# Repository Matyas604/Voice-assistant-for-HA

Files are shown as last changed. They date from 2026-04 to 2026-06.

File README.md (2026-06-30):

# Voice assistant for HA
A while back, I saw a YouTube video about a voice assistant for [Home Assistant](https://www.home-assistant.io/). I really liked that it activates when you say “Hey Jarvis” and can control various things via voice commands. 
And since I have Home Assistant set up, I thought, why not try building that assistant myself?

I found out that voice recognition can run on the [ESP32-S3-WROOM-1-N16R8](https://m5stack-doc.oss-cn-shenzhen.aliyuncs.com/1183/ESP32-S3-WROOM-1U-N16R8.pdf), so I decided to use it because it’s relatively inexpensive. 
Since I also wanted it to have a high-quality speaker for playing music, the total cost is quite high, but that’s because of the speaker, the custom PCB, and other components. 

I really enjoyed working on this project because I learned a lot of new things. For example, I learned how to properly design a speaker enclosure, since sound quality depends more on the enclosure than on the speaker itself.

## Features
- Power and programming are handled via the **USB-C** port on the back
- The [ESP32-S3](https://m5stack-doc.oss-cn-shenzhen.aliyuncs.com/1183/ESP32-S3-WROOM-1U-N16R8.pdf) is the brain of the entire voice assistant
- It uses **Groq AI**, **GroqTTS**, and **Groq STT**, so it can speak and understand many languages
- It's not just a voice assistant for commands, but also a great AI assistant
- It has internet access, so it can search for information and use it to provide answers
- Everything is accompanied by a light response, so you know exactly what's going on
- It's also a great music player because it features a high-quality [DAYTON DMA45-4](https://www.reproobchod.cz/user/related_files/dma45-4.pdf) speaker
- It has a touch button to mute the assistant hidden in the top cover.

<p align="center">
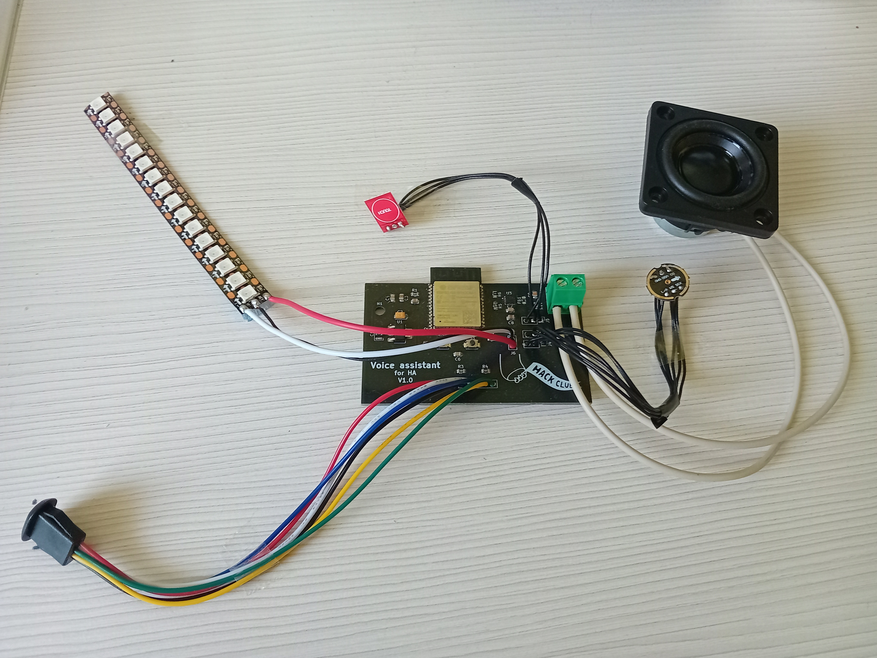
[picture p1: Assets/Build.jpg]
  
</p>

⚠️As you can see, the project is fully functional, but it’s missing the case because I had a few issues with the printer in printing legion and it didn’t arrive in time for the deadline. That’s why I’m submitting it to the build review like this for now, but as soon as the case arrives, I’ll document it again. Thank you

I really enjoyed designing and then building this project, especially because it works absolutely great. There was one error in the PCB (it’s already been corrected in the schematic and files), but fortunately it wasn’t a huge one and was easy to fix. This was actually my first project to include SMD components, and I soldered it by hand. The hardest part was soldering the amplifier chip, but luckily I managed to do it in the end!

Now, here's how it works: Once it's set up correctly, all you have to do is say "Hey Jarvis" and give your command or ask your question, and it will respond immediately or perform the action you requested. [Here](https://github.com/Matyas604/Voice-assistant-for-HA/blob/main/How%20to%20Set%20It%20Up.md) are the complete instructions on how to set it up.

## CAD model
Everything is housed in a box consisting of 5 parts (front panel, rear panel, top panel, body, and a tube connecting the outside to the inside chamber). The touch button is hidden in the top panel, so it can be activated by touch and is not visible from the outside. The interior space behind the speaker must be completely airtight at the front to function properly; it is connected to the outside only by a tube at the back. It is also a good idea to place a piece of cotton wool inside for better sound quality. The PCB is located separately from the space around the speaker; it is secured with M3 screws, just like the rear panel, while the top panel is held in place by magnets. 

<p align="center">
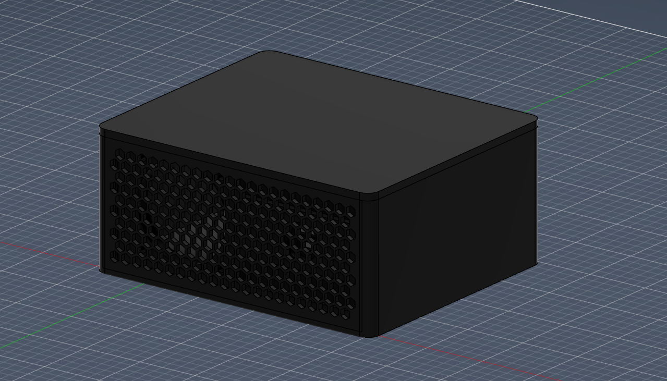
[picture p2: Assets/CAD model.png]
CAD model
  
</p>
<p align="center">
  <strong>Made in Fusion360</strong>
</p>

## PCB
<p align="center">
  Schematic
</p>
<p align="center">
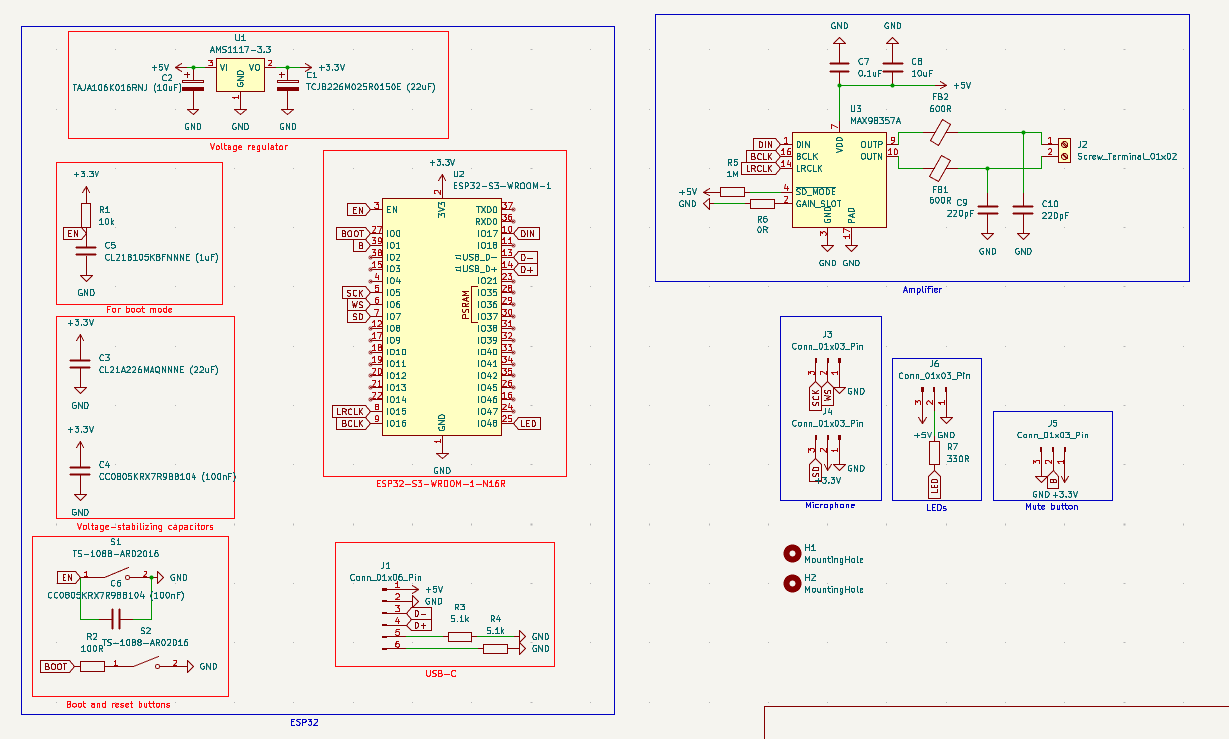
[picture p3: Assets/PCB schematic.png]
PCB schematic
  
</p>
<p align="center">
  PCB
</p>
<p align="center">
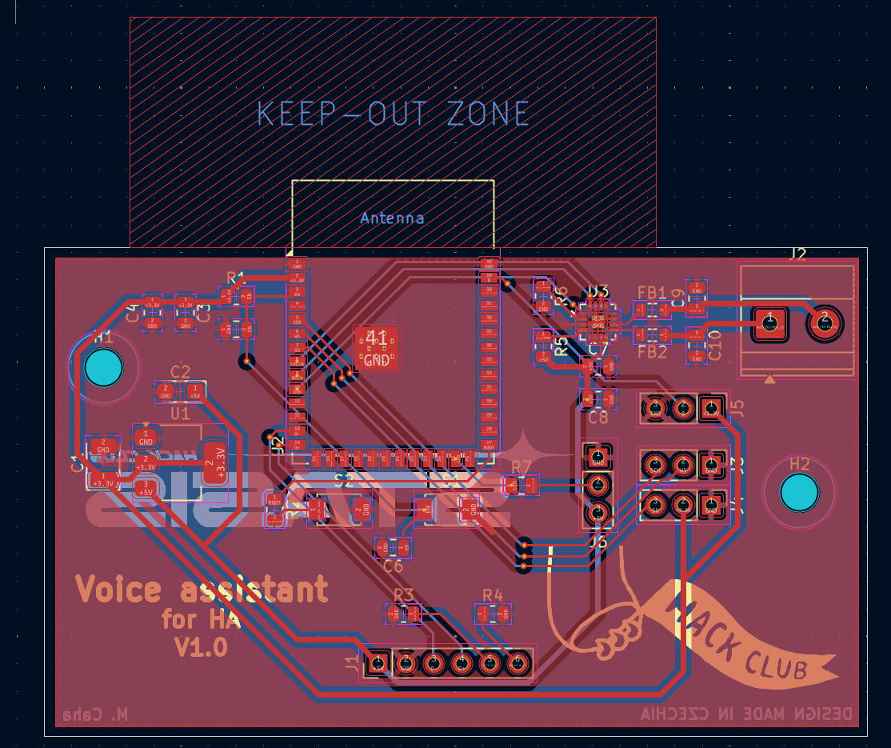
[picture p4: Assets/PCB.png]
PCB
  
</p>
<p align="center">
  <strong>Made in KiCad</strong>
</p>

## Firmware
This voice assistant uses [ESPHome](https://esphome.io/) firmware. It is programmed via the USB-C port. It is activated by saying "Hey Jarvis" and sends a recording of the command to the [Home Assistant](https://www.home-assistant.io/), where it is converted to text using **Groq STT**, then converted into a response using **Groq AI**, and then converted into a voice response using **Groq TTS**, the action is performed, and the response is spoken. You need to have the voice assistant pipeline set up correctly in Home Assistant tutorial [here](https://github.com/Matyas604/Voice-assistant-for-HA/blob/main/How%20to%20Set%20It%20Up.md)!

## BOM
You can find it in .csv format [here](https://github.com/Matyas604/Voice-assistant-for-HA/blob/main/BOM.csv). 

<hr>

<p align="center">
  Made with ❤️ by <a href="https://github.com/Matyas604">@Matyas604</a>
</p>

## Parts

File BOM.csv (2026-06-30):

Name | Purpose | Quantity | Total Cost (USD) | Link | Distributor
5x2mm Neodymium magnets | To attach the top panel to the main body of the assistant | 8 | 5.89 | https://www.aliexpress.com/item/1005009997504404.html | Aliexpress
3D printed parts | The whole assistant's case | 5 | 10.00 | https://printlegion.hackclub.com/ | Printing legion
DAYTON DMA45-4 | Speaker for the assistant | 1 | 20.61 | https://www.reproobchod.cz/dayton-dma45-4/ | Reproobchod.cz
M3 4mm screw | For mounting the PCB in the enclosure and attaching the back panel | 2 | 2.48 | https://www.aliexpress.com/item/4000981220901.html | Aliexpress
M3 6mm screw | For mounting the PCB in the enclosure and attaching the back panel | 2 | 2.45 | https://www.aliexpress.com/item/4000981220901.html | Aliexpress
M3 Heat Inserts | For mounting the PCB in the enclosure and attaching the back panel | 4 | 2.79 | https://www.aliexpress.com/item/1005008666672949.html | Aliexpress
WS2812B LED strip 1m | LEDs for feedback and status indication of the assistant | 1 | 8.17 | https://www.aliexpress.com/item/1005007995331885.html | Aliexpress
TTP223 Capacitive Touch Switch Button | Assistant control button | 1 | 2.58 | https://www.aliexpress.com/item/1005006087171183.html | Aliexpress
INMP441 Microphone Module | Microphone | 1 | 5.96 | https://www.aliexpress.com/item/1005007533809252.html | Aliexpress
USB-C connector | USB-C port for power and programming | 1 | 3.12 | https://www.aliexpress.com/item/1005007144793925.html | Aliexpress
Stencil | Stencil for applying solder paste to a PCB | 1 | 3.05 | https://jlcpcb.com/ | JLCPCB
PCB | PCB | 1 | 2.00 | https://jlcpcb.com/ | JLCPCB
MPZ2012S601AT000 | Ferrite filters for audio signals to the speaker 600Ω@100MHz | 2 | 0.27 | https://www.lcsc.com/product-detail/C21519.html | LCSC
0805W8F3300T5E | Resistor for LEDs 330R | 1 | 0.29 | https://www.lcsc.com/product-detail/C17630.html | LCSC
0805W8F0000T5E | Resistor for an amplifier 0R | 1 | 0.21 | https://www.lcsc.com/product-detail/C17477.html | LCSC
0805W8F1004T5E | Resistor for an amplifier 1M | 1 | 0.25 | https://www.lcsc.com/product-detail/C17514.html | LCSC
CL21A106KBYQNNE | Capacitors for an amplifier 10uF | 1 | 0.24 | https://www.lcsc.com/product-detail/C2932476.html | LCSC
CL21B104KCFNNNE | Capacitor for an amplifier 100nF | 1 | 0.49 | https://www.lcsc.com/product-detail/C28233.html | LCSC
0805B221K500NT | Capacitors for an amplifier 220pF | 2 | 0.55 | https://www.lcsc.com/product-detail/C1727.html | LCSC
WJ500V-5.08-2P | Connector for connecting a speaker to a PCB | 1 | 0.66 | https://www.lcsc.com/product-detail/C8465.html | LCSC
MAX98357AETE+T | Amplifier | 1 | 1.41 | https://www.lcsc.com/product-detail/C910544.html | LCSC
2.54-1*20P | Pins for connecting additional components to the PCB | 1 | 0.72 | https://www.lcsc.com/product-detail/C50981.html | LCSC
ESP32-S3-WROOM-1-N16R8 | Microcontroller for the whole project | 1 | 5.21 | https://www.lcsc.com/product-detail/C2913202.html?s_z=n_C2913202 | LCSC
0805W8F5101T5E | Resistor for ESP32 5.1k | 2 | 0.24 | https://www.lcsc.com/product-detail/C27834.html | LCSC
0805W8F1000T5E | Resistor for ESP32 100R | 1 | 0.21 | https://www.lcsc.com/product-detail/C17408.html | LCSC
RC0805FR-0710KL | Resistor for ESP32 10k | 1 | 0.31 | https://www.lcsc.com/product-detail/C84376.html | LCSC
TS-1088-AR02016 | Boot and reset buttons for the ESP32 | 2 | 0.55 | https://www.lcsc.com/product-detail/C720477.html?s_z=n_TS-1088-AR02016 | LCSC
CC0805KRX7R9BB104 | Capacitor for ESP32 100nF | 2 | 0.51 | https://www.lcsc.com/product-detail/C49678.html?s_z=n_CC0805KRX7R9BB104 | LCSC
CL21B105KBFNNNE | Capacitor for ESP32 1uF | 1 | 0.27 | https://www.lcsc.com/product-detail/C28323.html?s_z=n_CL21B105KBFNNNE | LCSC
CL21A226MAQNNNE | Capacitor for ESP32 22uF | 1 | 0.64 | https://www.lcsc.com/product-detail/C45783.html?s_z=n_CL21A226MAQNNNE | LCSC
TAJA106K016RNJ | Capacitor for a voltage converter 10uF | 1 | 0.25 | https://www.lcsc.com/product-detail/C7171.html?s_z=n_TAJA106K016RNJ%2520 | LCSC
25TQC22MYFB | Capacitor for a voltage converter 22uF | 1 | 0.80 | https://www.lcsc.com/product-detail/C3018703.html | LCSC
AMS1117-3.3 | Voltage Converter for ESP32 | 1 | 0.45 | https://www.lcsc.com/product-detail/C347222.html?s_z=n_AMS1117 | LCSC
Shipping | Total shipping cost |  | 25.75 |  | JLCPCB, LCSC, Reproobchod.cz
Tax | Total tax cost |  | 6.57 |  | JLCPCB, LCSC

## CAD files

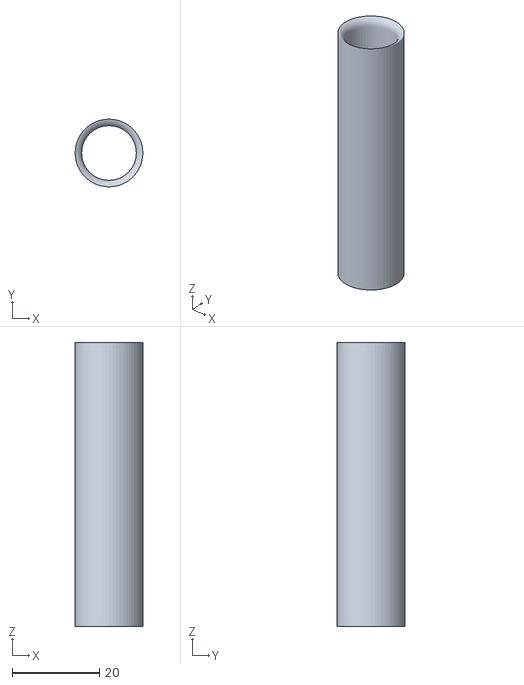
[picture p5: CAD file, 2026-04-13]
Production/3D parts/Port.stl
15.5 x 15.5 x 65.0

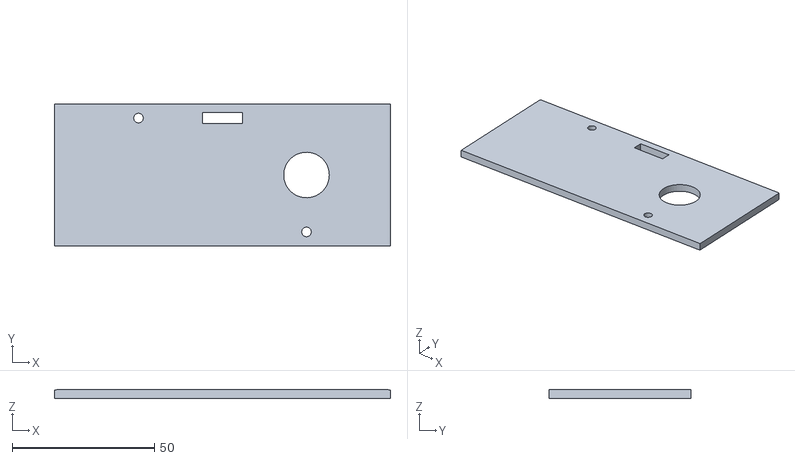
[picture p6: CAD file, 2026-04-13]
Production/3D parts/Back panel.stl
118.0 x 50.0 x 3.00

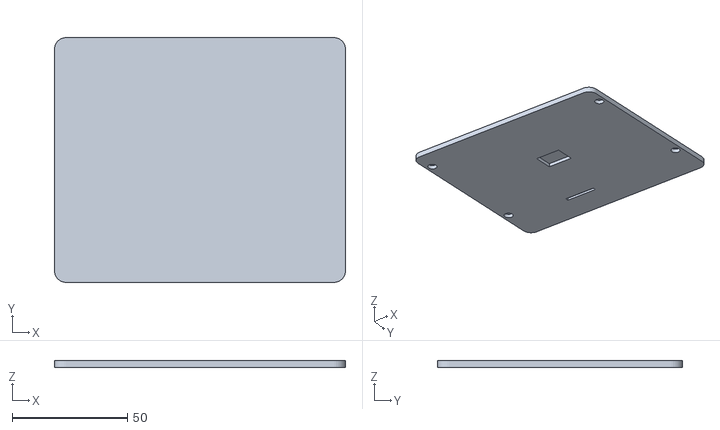
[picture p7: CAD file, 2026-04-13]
Production/3D parts/Lid.stl
126.0 x 106.0 x 3.00

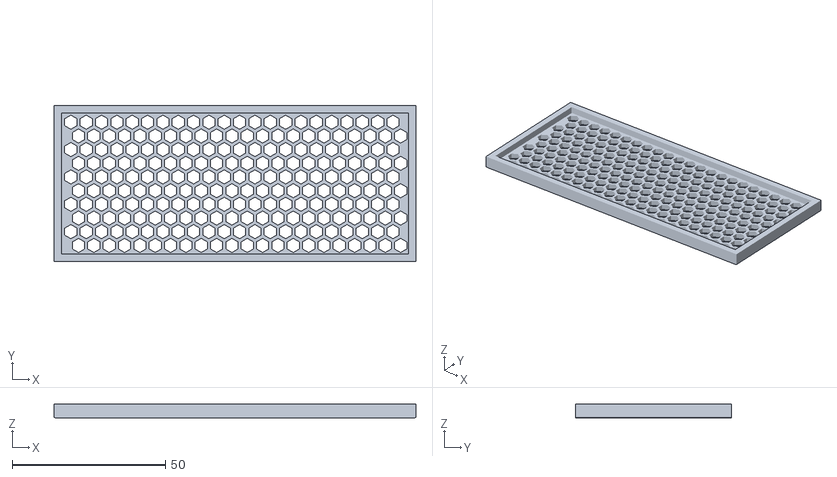
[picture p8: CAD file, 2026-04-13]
Production/3D parts/Front panel.stl
118.0 x 51.0 x 4.50

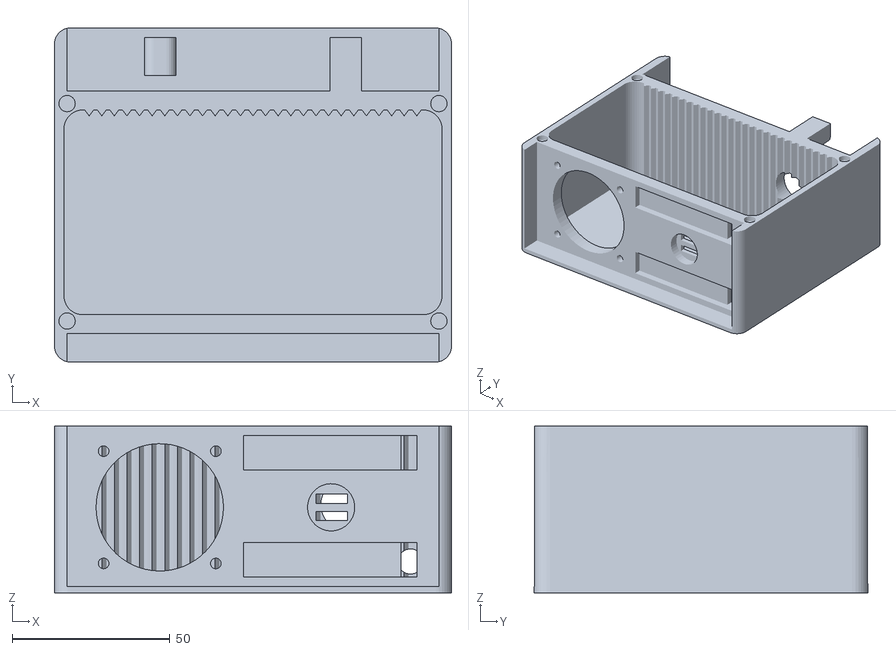
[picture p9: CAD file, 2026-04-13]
Production/3D parts/Enclosure.stl
126.0 x 106.0 x 53.0

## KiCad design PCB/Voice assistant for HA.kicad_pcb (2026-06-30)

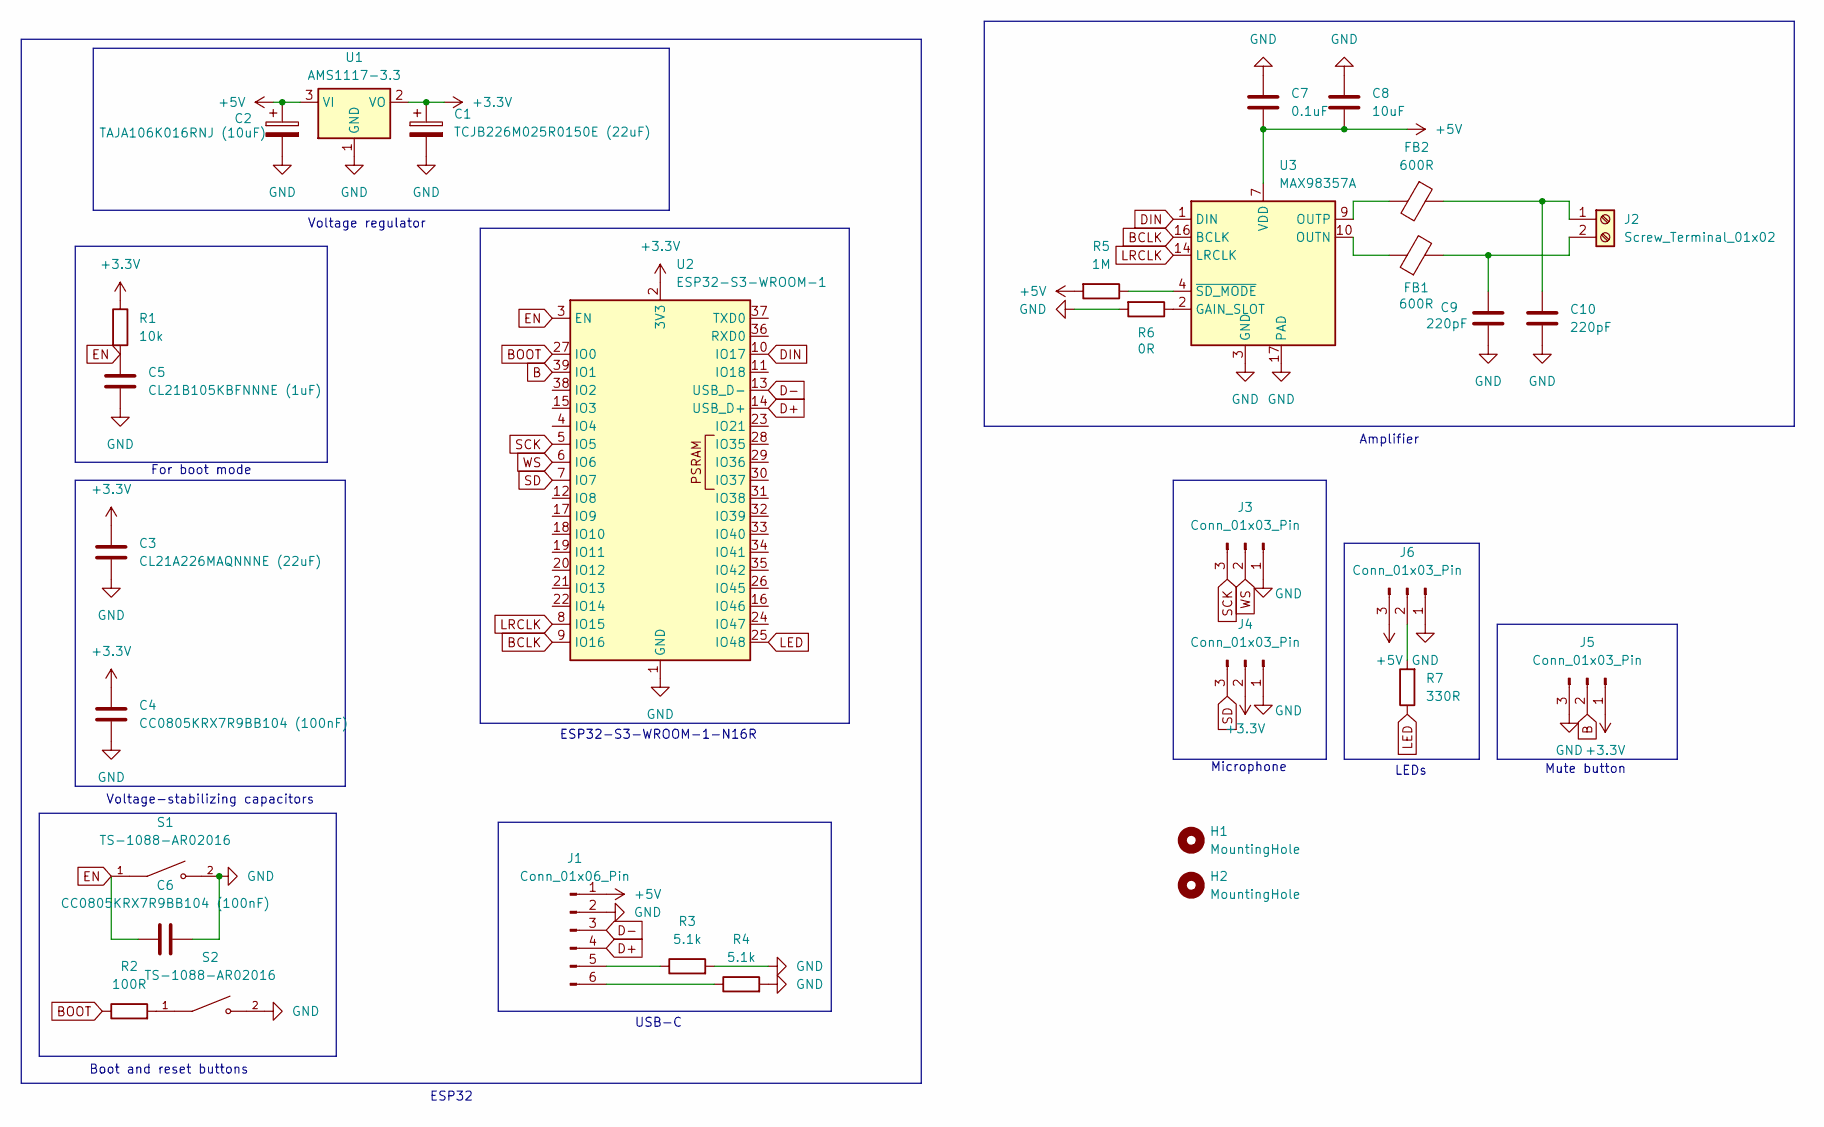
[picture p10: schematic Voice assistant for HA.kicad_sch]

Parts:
C1: TCJB226M025R0150E (22uF); CP_EIA-3528-21_Kemet-B
C2: TAJA106K016RNJ (10uF); CP_EIA-3216-18_Kemet-A
C3: CL21A226MAQNNNE (22uF); C_0805_2012Metric
C4, C6: CC0805KRX7R9BB104 (100nF); C_0805_2012Metric
C5: CL21B105KBFNNNE (1uF); C_0805_2012Metric
C7: 0.1uF; C_0805_2012Metric
C8: 10uF; C_0805_2012Metric
C9, C10: 220pF; C_0805_2012Metric
FB1, FB2: 600R; L_0805_2012Metric
H1, H2: MountingHole; MountingHole_3.2mm_M3
J1: Conn_01x06_Pin; PinHeader_1x06_P2.54mm_Vertical
J2: Screw_Terminal_01x02; TerminalBlock_Phoenix_MKDS-1,5-2_1x02_P5.00mm_Horizontal
J3, J4, J5, J6: Conn_01x03_Pin; PinHeader_1x03_P2.54mm_Vertical
R1: 10k; R_0805_2012Metric
R2: 100R; R_0805_2012Metric
R3, R4: 5.1k; R_0805_2012Metric
R5: 1M; R_0805_2012Metric
R6: 0R; R_0805_2012Metric
R7: 330R; R_0805_2012Metric
S1, S2: TS-1088-AR02016; SW_TS-1088-AR02016; PARTREV N/A
U1: AMS1117-3.3; SOT-223-3_TabPin2
U2: ESP32-S3-WROOM-1
U3: MAX98357A; TQFN-16-1EP_3x3mm_P0.5mm_EP1.23x1.23mm_ThermalVias

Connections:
+3.3V: C1.1, C3.1, C4.1, J4.2, J5.1, R1.1, U1.2 (VO), U2.2 (3V3)
+5V: C2.1, C7.2, C8.2, J1.1, J6.3, R5.2, U1.3 (VI), U3.7 (VDD), U3.8 (VDD)
B: J5.2, U2.39 (IO1)
BCLK: U2.9 (IO16), U3.16 (BCLK)
BOOT: R2.1, U2.27 (IO0)
D+: J1.4, U2.14 (USB_D+)
D-: J1.3, U2.13 (USB_D-)
DIN: U2.10 (IO17), U3.1 (DIN)
EN: C5.2, C6.1, R1.2, S1.1, U2.3 (EN)
GND: C1.2, C2.2, C3.2, C4.2, C5.1, C6.2, C7.1, C8.1, C9.2, C10.2, J1.2, J3.1, J4.1, J5.3, J6.1, R3.2, R4.2, R6.2, S1.2, S2.2, U1.1 (GND), U2.1 (GND), U2.40 (GND), U2.41 (GND), U3.3 (GND), U3.11 (GND), U3.15 (GND), U3.17 (PAD)
LED: R7.1, U2.25 (IO48)
LRCLK: U2.8 (IO15), U3.14 (LRCLK)
unnamed: J1.5, R3.1
unnamed: J1.6, R4.1
unnamed: C10.1, FB2.1, J2.1
unnamed: C9.1, FB1.2, J2.2
unnamed: J6.2, R7.2
unnamed: R2.2, S2.1
unnamed: R6.1, U3.2 (GAIN_SLOT)
unnamed: FB1.1, U3.10 (OUTN)
unnamed: FB2.2, U3.9 (OUTP)
unnamed: R5.1, U3.4 (~SD_MODE)
SCK: J3.3, U2.5 (IO5)
SD: J4.3, U2.7 (IO7)
WS: J3.2, U2.6 (IO6)

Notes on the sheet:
Voltage-stabilizing capacitors
LEDs
For boot mode
USB-C
Amplifier
Microphone
Mute button
ESP32
Voltage regulator
ESP32-S3-WROOM-1-N16R
Boot and reset buttons

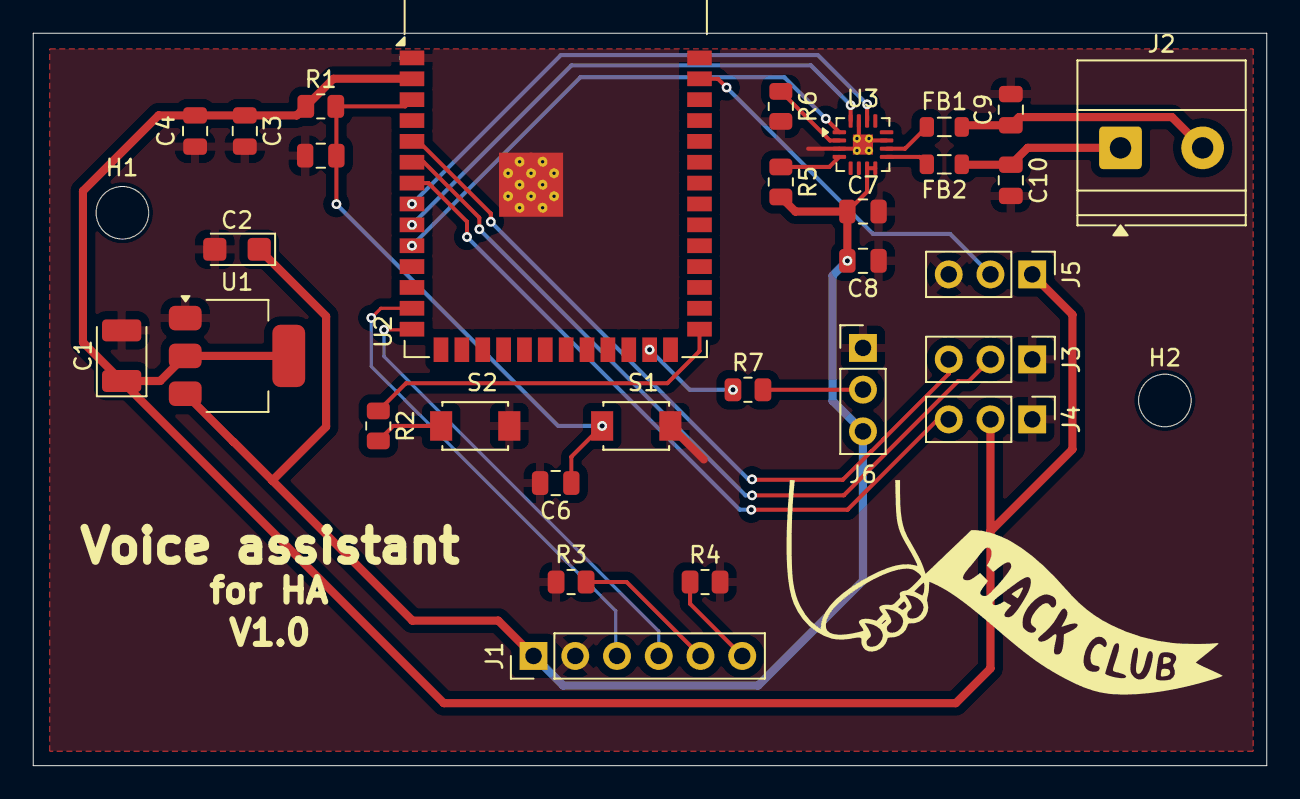
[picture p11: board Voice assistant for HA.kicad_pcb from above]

Board: 2 copper layers, 75.1 x 44.6 mm, 32 parts (0 on the bottom side), 25 nets.

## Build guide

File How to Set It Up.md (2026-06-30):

## How to Set Up the Assistant
First of all, you'll need to have [Home Assistant](https://www.home-assistant.io/) and the [ESPHome](https://esphome.io/) extension installed. If you don't know how to do that, search online! 

First, you need to download the .yaml code and edit the Wi-Fi settings in it; enter your information so that the board can connect to your Wi-Fi! Then, simply compile the code and download it.
### How to upload the code:
Open the [ESPHome](https://web.esphome.io/) page. Connect the board to your PC via USB-C (it must be a data cable—not just a power cable). 
Then click the “Connect” button. A port selection menu will open; this may vary by computer, but on mine, the port for the ESP was ```USB JTAG/Serial Debug Unit``` on port 5. 
The board may keep restarting and disconnecting—if so, simply unplug it, hold down the BOOT button, and plug it back in, then select it again on the page. 
Then just click the “Install” button and select the .bin file. After a moment, the code will upload, and the board should connect to Wi-Fi. It will then be visible in ESPHome and HA. 
If not, check the logs and try searching online.

<p align="center">
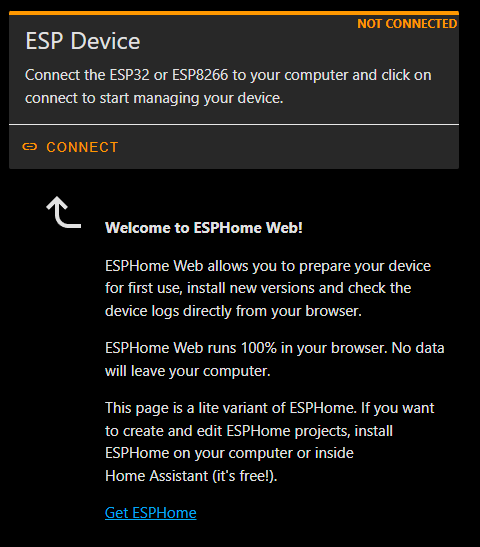
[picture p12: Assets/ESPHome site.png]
ESPHome site
  
</p>
<p align="center">
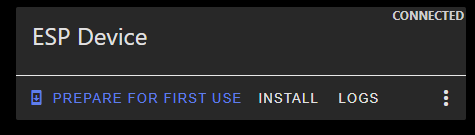
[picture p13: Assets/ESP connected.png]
ESP connected
  
</p>

An encryption key is required to connect to HA properly. It is in the code, or, if it hasn't been changed, it is "```R2iV3Cuc+P9gXfcOKZiR/pYnqE1fDyUBjXqoBMwdVm4=```". 
After successfully connecting and setting up HA, you still need to configure the "Assistant pipeline" for STT conversion and TTS.

## How to Set Up the Assistant Pipeline:
At first, I said it would work great with **Gemini**—and it does work great—but I found out that the limits without paying are really high. A maximum of 20 requests per day. 
So I looked for an alternative and found **Groq**, which has a lot of models, but most importantly, it also supports **STT**, and their limits are about 30 minutes of pure recording time per day for **STT** and, depending on the model, about 50–60 requests per day for answer. 
It’s calculated in tokens, so depending on the complexity of the command or question—the most complex or lengthy ones use **4,000 or 5,000 tokens**— **HA** sometimes sends them twice, so that’s about **10,000 tokens** for a complex command. The daily limit is **500,000 tokens**, so there’s a big reserve. 
Plus, this applies only to individual models, not overall, so once you’ve used up your limit, you just need to switch to a different model—and you can add more models in **HA**, unlike with **Gemini**. So, in my opinion, Groq is much better, but most importantly, it’s completely free for this. 
It also supports a huge amount of languages, so it doesn’t have to be just in **English**; I personally use **Czech**, and it works great.

First, you need to download the **Groq** integration for **HA**, since it isn't included automatically. Simply go to **HACS** to download it there, or download the **GitHub** library [here](https://github.com/barneyonline/ha-groq).



After successfully downloading and restarting **HA**, the integration will appear among the others as usual; just look for it in the list.



Now you need to create an account with **Groq** and generate an **API** key [here](https://console.groq.com/home). You can see them [here](https://console.groq.com/keys).



Now all you have to do is copy it, add the **Groq** integration in **HA**, and paste the **API** key there.



Now that you've successfully created it, all you need to do is add **STT**, the **AI** conversation model, and **TTS** one by one. I recommend following my settings because they work. For the **AI** conversation model, I recommend 
``` meta-llama/llama-4-scout-17b-16e-instruct ```
 because it has the highest daily usage limit; for STT, it doesn’t really matter—both have the same limits. And **TTS** is only available in English or Arabic.

![image](https://stasis.hackclub-assets.com/images/1782806418301-w5dx57.png)
 
![image](https://stasis.hackclub-assets.com/images/1782806451370-c5muqf.png)

![image](https://stasis.hackclub-assets.com/images/1782806481856-872tjd.png)

![image](https://stasis.hackclub-assets.com/images/1782806511729-mkbzf6.png)

If your language isn't listed in **STT**, first check whether **Groq STT** supports that language. If it does, simply go to ``` /home-assistant/config/custom_components/groq/const.py ```
 and in the section 
```STT_LANGUAGE_OPTIONS = [ ```
, add your language in the correct format. Save the file and restart HA. For example, this is how I added Czech, because Groq supports it but it wasn’t specified in the integration.

![image](https://stasis.hackclub-assets.com/images/1782806908491-fp4wfd.png)

```
    {"value": "cs-CZ", "label": "Czech"},
```
Once everything is set up, just go to **HA** Settings, Voice Assistants, and add a new assistant in Assist. Fill in all the fields with the **STT**, **TTS**, and **AI** conversation settings you configured, and add a name.

![Snímek obrazovky 2026-06-30 101927](https://stasis.hackclub-assets.com/images/1782807616660-fburn4.png)

Now all you have to do is select this configured chat assistant in the assistant settings.

![image](https://stasis.hackclub-assets.com/images/1782807752527-g1zr7b.png)

That's it—the assistant will now answer questions and control your home. Once the limit is reached, this model will no longer work, but you can switch to another one. The limit resets after 24 hours.The model limits are listed [here](https://console.groq.com/docs/rate-limits).

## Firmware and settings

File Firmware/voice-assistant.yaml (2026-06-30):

esphome:
  name: voice-assistant
  friendly_name: Voice assistant

esp32:
  board: esp32-s3-devkitc-1
  framework:
    type: esp-idf

# Enable logging
logger:

# Enable Home Assistant API
api:
  encryption:
    key: "R2iV3Cuc+P9gXfcOKZiR/pYnqE1fDyUBjXqoBMwdVm4="

ota:
  - platform: esphome
    password: "bee9620533a9ceb1bcd9e68c3a73b3b6"

wifi:
  ssid: !secret wifi_ssid
  password: !secret wifi_password

  # Enable fallback hotspot (captive portal) in case wifi connection fails
  ap:
    ssid: "Voice-Assistant Fallback Hotspot"
    password: "K8SjwEbvER5X"

captive_portal:
  
psram:
  mode: octal
  speed: 80MHz

# Defining two independent I2S buses
i2s_audio:
  - id: i2s_in
    i2s_lrclk_pin: GPIO6
    i2s_bclk_pin: GPIO5
  
  - id: i2s_out
    i2s_lrclk_pin: GPIO15
    i2s_bclk_pin: GPIO16

# INMP441 Microphone
microphone:
  - platform: i2s_audio
    id: my_mic
    i2s_audio_id: i2s_in
    i2s_din_pin: GPIO7
    adc_type: external
    pdm: false
    channel: left
    bits_per_sample: 32bit

# MAX98357A Amplifier
speaker:
  - platform: i2s_audio
    id: my_speaker
    i2s_audio_id: i2s_out
    i2s_dout_pin: GPIO17
    dac_type: external
    sample_rate: 48000
    bits_per_sample: 32bit
    channel: mono

  - platform: mixer
    id: mixing_speaker
    output_speaker: my_speaker
    num_channels: 2
    source_speakers:
      - id: announcement_mixing_input
        timeout: never
      - id: media_mixing_input
        timeout: never

  - platform: resampler
    id: announcement_resampling_speaker
    output_speaker: announcement_mixing_input
    sample_rate: 48000
    bits_per_sample: 16
  - platform: resampler
    id: media_resampling_speaker
    output_speaker: media_mixing_input
    sample_rate: 48000
    bits_per_sample: 16

# Media Player
media_player:
  - platform: speaker
    name: "Assistant Speaker"
    id: assistant_media_player
    announcement_pipeline:
      speaker: announcement_resampling_speaker
      format: FLAC     
      num_channels: 1 
      sample_rate: 48000
    media_pipeline:
      speaker: media_resampling_speaker
      format: FLAC
      num_channels: 2
      sample_rate: 48000

micro_wake_word:
  microphone: my_mic
  stop_after_detection: false
  vad:
  models:
    - model: hey_jarvis
      id: hey_jarvis
    - model: okay_nabu
      id: okay_nabu
  id: mww
  on_wake_word_detected:
    - light.turn_on:
        id: led_strip
        red: 0%
        green: 0%
        blue: 100%
        effect: "Pulse"
    - voice_assistant.start:
        wake_word: !lambda return wake_word;

voice_assistant:
  id: va
  microphone: my_mic
  media_player: assistant_media_player
  micro_wake_word: mww
  use_wake_word: false
  
  on_listening:
    - light.turn_on:
        id: led_strip
        red: 0%
        green: 0%
        blue: 100%
        effect: "Pulse"
  on_stt_end:
    - light.turn_on:
        id: led_strip
        red: 0%
        green: 100%
        blue: 0%
        effect: "None"
  on_tts_start:
    - light.turn_on:
        id: led_strip
        red: 100%
        green: 100%
        blue: 100%
        brightness: 50%
  on_tts_end:
    - light.turn_off: led_strip
  on_error:
    - light.turn_on:
        id: led_strip
        red: 100%
        green: 0%
        blue: 0%
        effect: "None"
    - delay: 2s
    - light.turn_off: led_strip

# LED strip
light:
  - platform: esp32_rmt_led_strip
    id: led_strip
    name: "Assistant Light"
    pin: GPIO48
    num_leds: 16
    rgb_order: GRB
    chipset: WS2812
    effects:
      - pulse:
          name: "Pulse"
      - addressable_rainbow:
          name: "Rainbow"
    
binary_sensor:
  - platform: gpio
    name: "Touch Button"
    pin: GPIO1
    on_press:
      - switch.toggle: mute_switch

# Mute button
switch:
  - platform: template
    name: "Mute the assistant"
    id: mute_switch
    optimistic: true
    icon: "mdi:microphone-off"
    turn_on_action:
      - voice_assistant.stop:
      - micro_wake_word.stop: 
      - light.turn_on:
          id: led_strip
          red: 100%
          green: 0%
          blue: 0%
          brightness: 15%
          effect: "None"
    turn_off_action:
      - micro_wake_word.start: 
      - light.turn_off: led_strip

# Volume slider
number:
  - platform: template
    name: "Assistant Volume"
    id: volume_control
    icon: "mdi:volume-high"
    min_value: 0
    max_value: 100
    step: 5
    initial_value: 50
    optimistic: true
    on_value:
      - speaker.volume_set:
         id: my_speaker
         volume: !lambda "return x / 100.0;"

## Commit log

2026-04-13 Adding files
    [Back panel.stl, Enclosure.stl, Front panel.stl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]
2026-04-13 Adding gerbers
2026-04-14 Adding BOM
    [BOM.csv]
2026-04-14 Final fix
    [BOM.csv]
2026-04-14 Adding CAD photo
2026-04-14 Adding PCb photos
2026-06-30 post-assembly adjustments
    [BOM.csv, Voice assistant for HA.kicad_pcb, Voice assistant for HA.kicad_sch]
